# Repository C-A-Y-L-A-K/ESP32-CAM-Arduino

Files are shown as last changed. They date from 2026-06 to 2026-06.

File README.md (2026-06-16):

# 🤖 ESP32-CAM Otonom Güvenlik Botu (Görüntü İşleme ve Takip Sistemi)

Bu proje, **ESP32-CAM** tabanlı, etrafı 180 derece tarayabilen ve Python üzerinde çalışan bir OpenCV yazılımı ile "Kırmızı ve Dairesel" tehlikeli nesneleri otonom olarak tespit eden akıllı bir güvenlik sistemidir. Arduino IDE ve Python kullanılarak geliştirilmiştir.

## 🎯 Özellikler
- **Wi-Fi Görüntü Aktarımı**: ESP32-CAM üzerinden bilgisayara düşük gecikmeli, kablosuz JPEG görüntü aktarımı.
- **Otonom 180 Derece Tarama**: Radar mantığıyla çalışan SG90 servo motor ile sürekli alan taraması (500us - 2500us arası tam 180 derece tarama).
- **Akıllı Görüntü Analizi**: Görüntüdeki kırmızı, dairesel (yuvarlaklık oranı yüksek) nesnelerin OpenCV ile algılanması ve hedefe kilitlenme.
- **Alarm Sistemi**: Tehlike (hedef) algılandığında veya manuel olarak tetiklendiğinde çalışan Buzzer sistemi ve hedefe dönük şekilde kilitlenen servo motor.
- **Uzaktan Debug (Hata Ayıklama)**: ESP32'nin C++ arka plan loglarını USB kablosuna ihtiyaç duymadan kablosuz (HTTP `/log` üzerinden) doğrudan Python konsoluna aktarabilme.
- **Çift Modlu Çalışma**: 
  - *Otonom Mod*: Sistem kendini tarar, hedefini arar.
  - *Manuel Mod*: Analiz devre dışı bırakıldığında `Z` ve `X` tuşları ile servo motor bilgisayardan kontrol edilebilir, flaş ve siren açılıp kapatılabilir.

## 🛠️ Kullanılan Donanım Parçaları
- 1 adet **ESP32-CAM Modülü** (Kamera kartı)
- 1 adet **SG90 Servo Motor** (Radar taraması için)
- 1 adet **Buzzer** (Alarm/Siren için)
- Jumper kablolar ve Güç Kaynağı (Batarya veya 5V adaptör)

### Devre / Pin Bağlantıları
| Bileşen | ESP32-CAM Pini | Görevi |
| --- | --- | --- |
| **Buzzer** | `GPIO 14` | Tehlike anında sesli ikaz |
| **Servo Motor** | `GPIO 15` | Kamera yönlendirmesi (180 derece) |
| **Dahili Flaş LED**| `GPIO 4` | Gece görüşü için aydınlatma (Modül üzerinde mevcut) |

---

## 🧠 Çalışma Mantığı ve Algoritma

Sistem iki ana parçadan oluşur: **ESP32-CAM (Sunucu)** ve **Python Analiz Scripti (İstemci)**.

### 1. ESP32-CAM (C++ / Arduino) Algoritması
ESP32, bir Web Sunucusu (HTTP Server) oluşturarak yerel ağda yayın yapar. 
- **Çoklu Uç Noktalar (Endpoints)**: `/stream` ile videoyu aktarır, `/servo`, `/alarm`, `/scan`, `/control`, ve `/log` ile gelen komutları anında donanıma yansıtır.
- **Asenkron Motor Kontrolü**: `loop()` fonksiyonu içinde `delay()` kullanmadan (adım gecikmeleri ile bloklama yapmadan), servoyu çevirerek "radar" taramasını yapar. Eğer Python tarafından alarm veya "manuel mod" sinyali gelirse (`auto_scan_state = false`), motor otomatik taramayı anında keser.
- **Donanımsal PWM**: Servo kontrolleri için ESP32'nin donanımsal `ledc` kütüphanesi (50Hz sinyal) kullanılır.

### 2. Python OpenCV (Görüntü İşleme) Algoritması
Görüntüler ağ üzerinden alınır ve bir sonsuz döngü içerisinde kare kare (`frame`) işlenir:
1. **Renk Filtreleme (HSV)**: Görüntü BGR formatından HSV (Ton, Doygunluk, Parlaklık) formatına çevrilir. Sadece kırmızı renk aralığına uygun olan pikselleri ayırmak için bir maske (`cv2.inRange`) oluşturulur.
2. **Gürültü Temizleme (Filtreleme)**: Oluşan maskeye medyan filtresi (`cv2.medianBlur`) uygulanarak sensör kirliliğinden kaynaklanan ufak parazitler silinir.
3. **Kontur Bulma ve Geometrik Analiz**: Filtrelenmiş maskede kalan adacıkların (konturların) alan ve çevre uzunluğu hesaplanır (`cv2.arcLength` ve `cv2.contourArea`).
4. **Dairesellik Formülü**: `(4 * π * Alan) / (Çevre²)` formülü kullanılarak nesnenin ne kadar yuvarlak olduğu bulunur. Bu oran %70'in üzerindeyse ve alan çok küçük değilse (yanılsama değilse), hedefin etrafına yeşil çember ve merkezine kırmızı nişangah çizilir.
5. **Aksiyon Alma**: Hedef tespit edildiği an ESP32'ye HTTP isteği ile Alarm komutu gönderilir. Motor taramayı durdurup hedefe kilitlenir.

---

## 🚀 Kurulum ve Kullanım

### Adım 1: ESP32-CAM Kodunun Yüklenmesi
1. Arduino IDE üzerinden `CameraWebServer.ino` dosyasını açın.
2. Kod içerisindeki Wi-Fi adı (`ssid`) ve şifrenizi (`password`) kendi ağınıza göre değiştirin.
3. ESP32-CAM kartınıza FTDI (USB to TTL) programlayıcı kullanarak kodu yükleyin.
4. Serial Monitörü açarak ESP32'nin aldığı IP adresini not edin.

### Adım 2: Python Scriptinin Hazırlanması
Bilgisayarınızda Python yüklü olmalıdır. Gerekli kütüphaneleri kurmak için terminali/CMD'yi açıp şu komutu girin:
```bash
pip install opencv-python numpy requests
```

### Adım 3: Çalıştırma
1. `guvenlik_analiz.py` dosyasını bir metin editörü ile açın.
2. 11. satırdaki `esp32_ip = '...'` kısmına, Arduino IDE'de not ettiğiniz IP adresini yazın.
3. ESP32'nize pilden veya adaptörden güç verin. Bilgisayara bağlı olmasına gerek yoktur.
4. Terminal üzerinden Python scriptini çalıştırın:
```bash
python guvenlik_analiz.py
```

### 🎮 Klavye Kısayolları (Kontrol Merkezi)
Video penceresi aktifken aşağıdaki tuşları kullanarak sisteme müdahale edebilirsiniz:
- **`A` Tuşu:** Otonom Tarama ve Analizi Açar/Kapatır. (Kapatıldığında manuel moda geçer).
- **`Z` ve `X` Tuşları:** Manuel moddayken servoyu Sağa ve Sola döndürür.
- **`S` Tuşu:** Alarm/Sireni manuel olarak tetikler.
- **`F` Tuşu:** Kamera üzerindeki Flaş LED'i açıp kapatır.
- **`Q` Tuşu:** Güvenli şekilde sistemi durdurur ve çıkar.

---

*Bu proje güvenlik ve otomasyon algoritmalarını donanım gücüyle birleştirmek üzere geliştirilmiştir.*

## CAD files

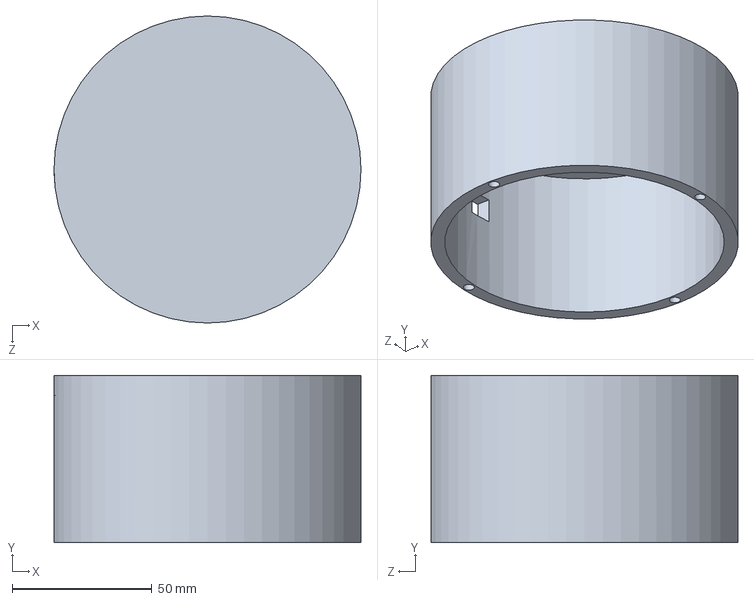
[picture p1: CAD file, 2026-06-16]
Arduino cizim/Kamera_Ust_Parca.SLDPRT
110.0 x 60.0 x 110.0 mm

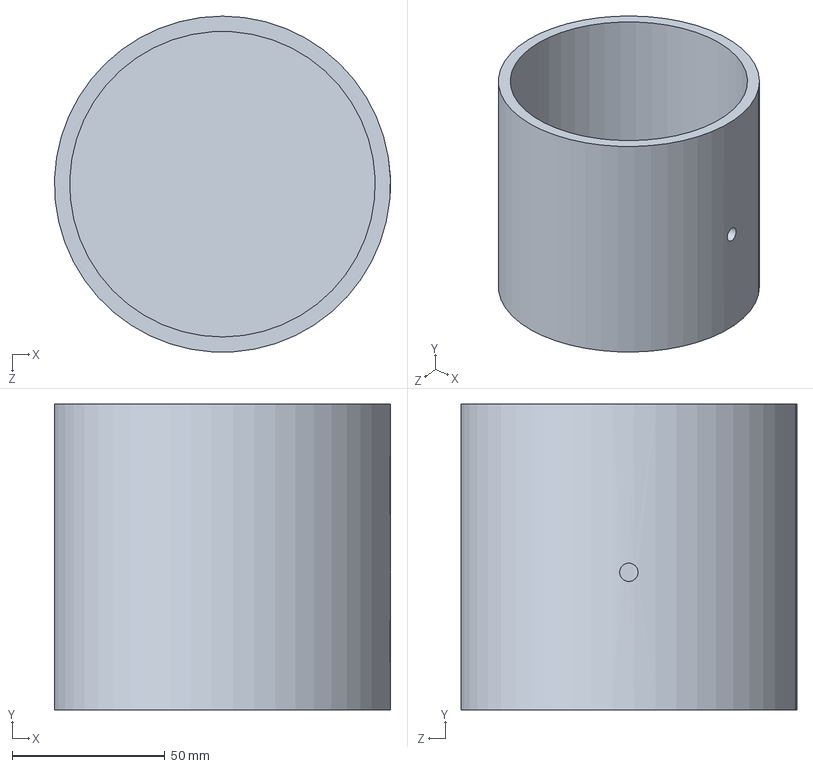
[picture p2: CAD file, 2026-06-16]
Arduino cizim/Kamera_Alt_Parca.SLDPRT
110.0 x 100.0 x 109.9 mm

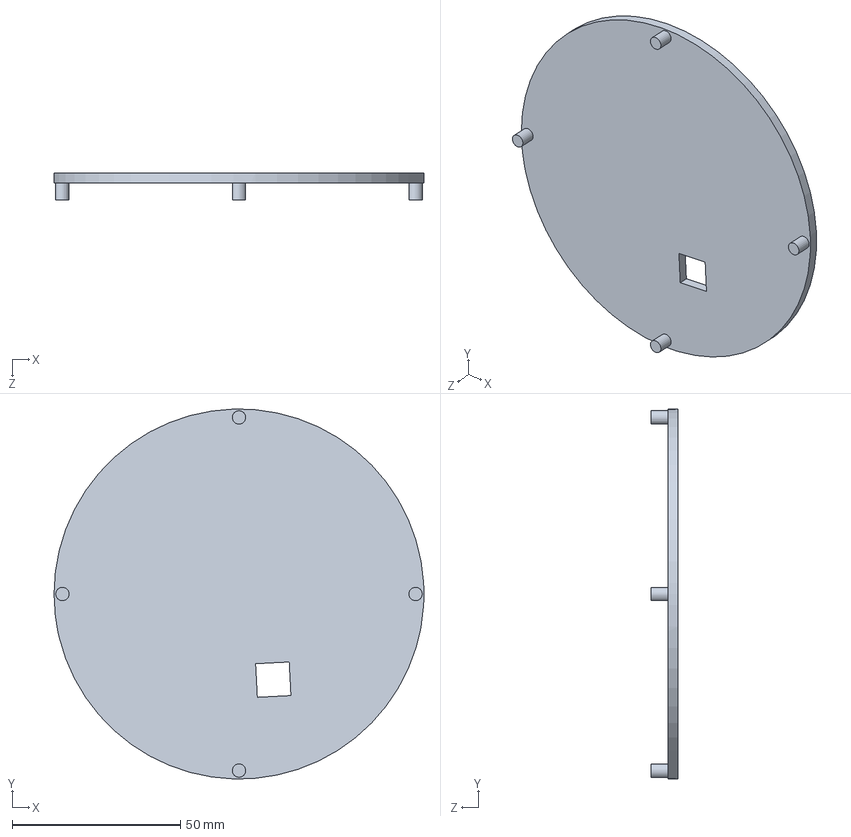
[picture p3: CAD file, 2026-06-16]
Arduino cizim/Kamera_Ara_Parca.SLDPRT
110.0 x 110.0 x 8.00 mm

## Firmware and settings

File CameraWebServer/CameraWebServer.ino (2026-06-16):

#include <Arduino.h>
#include "esp_camera.h"
#include <WiFi.h>

// app_httpd.cpp'de tanimlanan fonksiyon ve pin sabitlerine erisim
extern void setServoPosition(uint32_t pulse_us);
#define BUZZER_PIN       14
#define SERVO_PIN        15
#define SERVO_FREQ       50
#define SERVO_RES        16
#define SERVO_CENTER_US  1500

// ===========================
// Kamera modelini board_config.h dosyasindan secin
// ===========================
#include "board_config.h"

// ===========================
// WiFi bilgilerinizi girin
// ===========================

const char *ssid = "*****";          // Kamera ve uygulamanın aynı Ağa bağlı olması gerekmektedir.
const char *password = "*****";      // Kameranın WiFi şifresi

void startCameraServer();
void setupLedFlash();

void setup() {
  Serial.begin(115200);
  Serial.setDebugOutput(true);
  Serial.println();

  camera_config_t config;
  config.ledc_channel = LEDC_CHANNEL_0;
  config.ledc_timer = LEDC_TIMER_0;
  config.pin_d0 = Y2_GPIO_NUM;
  config.pin_d1 = Y3_GPIO_NUM;
  config.pin_d2 = Y4_GPIO_NUM;
  config.pin_d3 = Y5_GPIO_NUM;
  config.pin_d4 = Y6_GPIO_NUM;
  config.pin_d5 = Y7_GPIO_NUM;
  config.pin_d6 = Y8_GPIO_NUM;
  config.pin_d7 = Y9_GPIO_NUM;
  config.pin_xclk = XCLK_GPIO_NUM;
  config.pin_pclk = PCLK_GPIO_NUM;
  config.pin_vsync = VSYNC_GPIO_NUM;
  config.pin_href = HREF_GPIO_NUM;
  config.pin_sccb_sda = SIOD_GPIO_NUM;
  config.pin_sccb_scl = SIOC_GPIO_NUM;
  config.pin_pwdn = PWDN_GPIO_NUM;
  config.pin_reset = RESET_GPIO_NUM;
  config.xclk_freq_hz = 20000000;
  config.frame_size = FRAMESIZE_UXGA;
  config.pixel_format = PIXFORMAT_JPEG;  // for streaming
  //config.pixel_format = PIXFORMAT_RGB565; // for face detection/recognition
  config.grab_mode = CAMERA_GRAB_WHEN_EMPTY;
  config.fb_location = CAMERA_FB_IN_PSRAM;
  config.jpeg_quality = 12;
  config.fb_count = 1;

  // Eger PSRAM entegresi varsa, daha buyuk on bellek tahsisi icin
  // UXGA cozunurlugu ve daha yuksek JPEG kalitesi ile baslat.
  if (config.pixel_format == PIXFORMAT_JPEG) {
    if (psramFound()) {
      config.jpeg_quality = 10;
      config.fb_count = 2;
      config.grab_mode = CAMERA_GRAB_LATEST;
    } else {
      // PSRAM yoksa cerceve boyutunu sinirla
      config.frame_size = FRAMESIZE_SVGA;
      config.fb_location = CAMERA_FB_IN_DRAM;
    }
  } else {
      // Yuz algilama/tanima icin en iyi secenek
      config.frame_size = FRAMESIZE_240X240;
#if CONFIG_IDF_TARGET_ESP32S3
    config.fb_count = 2;
#endif
  }

#if defined(CAMERA_MODEL_ESP_EYE)
  // NOT: Biz bu modeli kullanmiyoruz, pin 14 bizde Buzzer icin kullaniliyor.
  // pinMode(13, INPUT_PULLUP);
  // pinMode(14, INPUT_PULLUP);
#endif

  // Kamerayi baslat
  esp_err_t err = esp_camera_init(&config);
  if (err != ESP_OK) {
    Serial.printf("Kamera baslatilamadi, hata kodu 0x%x", err);
    return;
  }

  sensor_t *s = esp_camera_sensor_get();
  // ilk sensorler dikey olarak ters cevrilmistir ve renkler biraz doygun olabilir
  if (s->id.PID == OV3660_PID) {
    s->set_vflip(s, 1);        // geri dondur
    s->set_brightness(s, 1);   // parlakligi biraz artir
    s->set_saturation(s, -2);  // doygunlugu azalt
  }
  // daha yuksek baslangic kare hizi icin cerceve boyutunu dusur
  if (config.pixel_format == PIXFORMAT_JPEG) {
    s->set_framesize(s, FRAMESIZE_QVGA);
  }

#if defined(CAMERA_MODEL_M5STACK_WIDE) || defined(CAMERA_MODEL_M5STACK_ESP32CAM)
  s->set_vflip(s, 1);
  s->set_hmirror(s, 1);
#endif

#if defined(CAMERA_MODEL_ESP32S3_EYE)
  s->set_vflip(s, 1);
#endif

// Eger camera_pins.h icinde LED pini tanimlanmissa LED Flas'i kur
#if defined(LED_GPIO_NUM)
  setupLedFlash();
#endif

  WiFi.begin(ssid, password);
  WiFi.setSleep(false);

  Serial.print("WiFi baglaniyor");
  while (WiFi.status() != WL_CONNECTED) {
    delay(500);
    Serial.print(".");
  }
  Serial.println("");
  Serial.println("WiFi baglandi");

  startCameraServer();

  // ============================================================
  // --- ALARM DONANIMLARINI BASLAT ---
  // ============================================================
  // Buzzer: Standart dijital cikis (GPIO 14)
  pinMode(BUZZER_PIN, OUTPUT);
  digitalWrite(BUZZER_PIN, LOW); // Baslangicta sustur

  // Servo: LEDC donanim PWM'i startCameraServer'DAN ONCE baslat
  // (Kamera LEDC_TIMER_0 kullaniyor; servo farkli bir timer almali)
  ledcAttach(SERVO_PIN, SERVO_FREQ, SERVO_RES);
  setServoPosition(SERVO_CENTER_US);
  delay(300);

  startCameraServer();

  // ---- BASLANGIC TARAMA SÜPÜRMESİ (sol -> sag -> merkez) ----
  Serial.println("[SERVO]: Baslangic tarama surmesi basliyor...");

  // Motor guc stabilizasyonu icin bekliyoruz
  delay(1000);

  // 1. Adim: Sol uca git ve yerles
  setServoPosition(1000);
  delay(800);

  // 2. Adim: Sol uctan (1000µs) sag uca (2000µs) sur
  // Adim: 50µs (~4.5 derece) | Gecikme: 60ms
  // Toplam: (2000-1000)/50 = 20 adim x 60ms = ~1.2 saniye
  for (uint32_t us = 1000; us <= 2000; us += 50) {
    setServoPosition(us);
    delay(60);
  }
  delay(400);

  // 3. Adim: Sag uctan merkeze (1500µs) don
  setServoPosition(SERVO_CENTER_US);
  delay(600);
  Serial.println("[SERVO]: Tarama tamamlandi. Merkez konumda bekleniyor.");

  Serial.print("Kamera Hazir! Baglanmak icin 'http://");
  Serial.print(WiFi.localIP());
  Serial.println("' adresini kullanin");
}

extern volatile bool alarm_state;
extern volatile bool auto_scan_state;

void loop() {
  if (!alarm_state && auto_scan_state) {
    Serial.println("[DEBUG-MOTOR] Tarama dongusu basliyor: Sol -> Sag");
    // Sol uçtan (500us) sağ uca (2500us) tarama
    for (uint32_t us = 500; us <= 2500; us += 50) {
      if (alarm_state || !auto_scan_state) {
        Serial.println("[DEBUG-MOTOR] Tarama kesildi!");
        break;
      }
      setServoPosition(us);
      delay(60);
    }
    
    if (!alarm_state && auto_scan_state) {
      Serial.println("[DEBUG-MOTOR] Tarama dongusu donuyor: Sag -> Sol");
      // Sağ uçtan (2500us) sol uca (500us) geri dönüş
      for (uint32_t us = 2500; us >= 500; us -= 50) {
        if (alarm_state || !auto_scan_state) {
          Serial.println("[DEBUG-MOTOR] Tarama kesildi!");
          break;
        }
        setServoPosition(us);
        delay(60);
      }
    }
  } else {
    // Alarm aktifse veya tarama kapalıysa bekle
    delay(500);
  }
}

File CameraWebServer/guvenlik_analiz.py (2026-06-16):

import cv2
import numpy as np
import requests
import threading
import time
import math

# ==============================================================================
# --- BAĞLANTI VE AYARLAR ---
# ==============================================================================
esp32_ip    = '10.39.32.241'                      # ESP32-CAM kartının mevcut IP adresi
url         = f'http://{esp32_ip}:81/stream'      # Video akışının çekileceği stream adresi
control_url = f'http://{esp32_ip}/control'        # Flaş kontrolü için HTTP adresi
alarm_url   = f'http://{esp32_ip}/alarm'          # Alarm kontrolü için HTTP adresi
servo_url   = f'http://{esp32_ip}/servo'          # Manuel servo kontrolü için HTTP adresi
log_url     = f'http://{esp32_ip}/log'            # ESP32 uzaktan debug logları için HTTP adresi
scan_url    = f'http://{esp32_ip}/scan'           # Otomatik tarama kontrolü için HTTP adresi

# ==============================================================================
# --- SİSTEM DURUM DEĞİŞKENLERİ ---
# ==============================================================================
analiz_aktif  = True   # 'a' tuşu ile kontrol edilir (Otonom analiz Açık/Kapalı)
flas_aktif    = False  # 'f' tuşu ile kontrol edilir (ESP32 Flaş Açık/Kapalı)
manuel_alarm  = False  # 's' tuşu ile kontrol edilir (Manuel test sireni)

# Servo manuel kontrol değişkenleri
servo_pos     = 1500   # Başlangıç konumu: merkez (1500µs = 90°)
SERVO_MIN     = 500    # Sol sınır (~0°)
SERVO_MAX     = 2500   # Sağ sınır (~180°)
SERVO_ADIM    = 100    # Her tuş basışında kaç µs kayacak

fps_baslangic_zamani = 0  # FPS hesaplama için zaman tutucu
fps = 0                   # Anlık kare hızı değeri

# Alarm HTTP isteğinin video döngüsünü bloklamasını engellemek için son durum takibi
son_alarm_durumu = None   # None = henüz gönderilmedi, True/False = son gönderilen durum

print("=== [OTONOM GÜVENLİK BOTU - ESP32-CAM DOĞRUDAN KONTROL] ===")
print(f"[AĞ LOG]: Kamera akışı -> {url}")
print(f"[AĞ LOG]: Alarm kontrolü -> {alarm_url}")

# ==============================================================================
# FONKSİYON: ESP32-CAM FLAŞ (LED) KONTROL MEKANİZMASI
# ==============================================================================
def flas_degistir(durum):
    """ESP32 üzerindeki dahili flaş LED'ini HTTP istekleri ile açar veya kapatır."""
    try:
        val = 255 if durum else 0
        requests.get(f"{control_url}?var=led_intensity&val={val}", timeout=2)
        print(f"[KOMUT LOG]: Flaş durumu güncellendi -> {'AÇIK' if durum else 'KAPALI'}")
    except Exception as e:
        print(f"[HATA LOG]: Flaş komutu ESP32'ye ulaştırılamadı! Detay: {e}")

# ==============================================================================
# FONKSİYON: ESP32'YE HTTP ÜZERINDEN ALARM KOMUTU GÖNDER (Arduino Yok!)
# ==============================================================================
def alarm_gonder(durum):
    """
    ESP32'deki /alarm uç noktasına HTTP GET isteği gönderir.
    durum=True  -> Buzzer çal, Servo hareket ettir
    durum=False -> Buzzer sus, Servo merkeze dön
    Bu fonksiyon ayrı bir thread'de çalışır, video döngüsünü bloklamaz.
    """
    try:
        state_val = 1 if durum else 0
        requests.get(f"{alarm_url}?state={state_val}", timeout=2)
        print(f"[ALARM LOG]: ESP32'ye alarm komutu gönderildi -> state={state_val}")
    except Exception as e:
        print(f"[HATA LOG]: Alarm komutu ESP32'ye ulaştırılamadı! Detay: {e}")

def alarm_gonder_async(durum):
    """alarm_gonder fonksiyonunu arka planda ayrı thread ile çağırır."""
    t = threading.Thread(target=alarm_gonder, args=(durum,), daemon=True)
    t.start()

# ==============================================================================
# FONKSİYON: ESP32'YE HTTP ÜZERINDEN SERVO KOMUTU GÖNDER
# ==============================================================================
def servo_gonder(pos_us):
    """
    ESP32'deki /servo?pos=<us> uç noktasına HTTP GET isteği gönderir.
    Alarm aktifken ESP32 komutu zaten yoksayar.
    """
    try:
        requests.get(f"{servo_url}?pos={pos_us}", timeout=2)
    except Exception as e:
        print(f"[HATA LOG]: Servo komutu gönderilemedi! Detay: {e}")

def servo_gonder_async(pos_us):
    """servo_gonder fonksiyonunu arka planda ayrı thread ile çağırır."""
    t = threading.Thread(target=servo_gonder, args=(pos_us,), daemon=True)
    t.start()

# ==============================================================================
# FONKSİYON: ESP32 OTOMATİK TARAMA DURUMUNU DEĞİŞTİR
# ==============================================================================
def scan_gonder(durum):
    """ESP32'deki /scan uç noktasına HTTP GET isteği göndererek otomatik taramayı açar/kapatır."""
    try:
        state_val = 1 if durum else 0
        requests.get(f"{scan_url}?state={state_val}", timeout=2)
    except Exception as e:
        print(f"[HATA LOG]: Tarama komutu gönderilemedi! Detay: {e}")

def scan_gonder_async(durum):
    t = threading.Thread(target=scan_gonder, args=(durum,), daemon=True)
    t.start()

# ==============================================================================
# FONKSİYON: ESP32'DEN UZAKTAN DEBUG LOGLARINI ÇEK
# ==============================================================================
def log_cek_dongusu():
    """Arka planda saniyede bir ESP32'nin /log uç noktasını kontrol eder ve yeni logları ekrana basar."""
    while True:
        try:
            r = requests.get(log_url, timeout=2)
            if r.status_code == 200 and r.text.strip():
                for line in r.text.strip().split('\n'):
                    if line.strip():
                        print(f"[ESP32 C++ LOG]: {line.strip()}")
        except Exception:
            pass # Bağlantı hatası durumunda sessizce geç
        time.sleep(1) # Saniyede 1 kez sorgula

t_log = threading.Thread(target=log_cek_dongusu, daemon=True)
t_log.start()
print("[AĞ LOG]: ESP32 C++ Uzaktan Debug Log servisi dinleniyor...")

# ==============================================================================
# 2. ADIM: VİDEO AKIŞ DÖNGÜSÜ VE ANALİZ
# ==============================================================================
print(f"[AĞ LOG]: ESP32-CAM canlı yayını bekleniyor: {url}")
bytes_data = bytes()
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

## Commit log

2026-06-04 ESP32-CAM Kodları
    [partitions.csv]
2026-06-11 Arduino Kaldırıldı
